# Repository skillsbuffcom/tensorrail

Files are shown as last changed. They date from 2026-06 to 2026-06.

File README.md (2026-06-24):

# TensorRail-Mini — FPGA INT8 Systolic AI Accelerator Carrier Board



[]()

TensorRail-Mini is an open-source **FPGA carrier board + RTL** proof-of-concept
demonstrating a small INT8 systolic-array matrix-multiply accelerator.  It pairs an
off-the-shelf Lattice ECP5 Feather module (e.g. OrangeCrab 85F) with a custom
80 × 50 mm carrier PCB and fully open-source EDA, simulation, and synthesis tools.

> **Honesty notice** — No physical board has been fabricated or measured.
> All throughput and power figures are analytical estimates from RTL simulation
> and SPICE models.  The bring-up plan in [`docs/bringup_plan.md`](docs/bringup_plan.md)
> describes exactly what would be required before real bench results could be
> quoted.  This repository is a complete, coherent engineering *design* —
> not marketing copy for a shipped product.

---

## Why This Matters for AI / Semiconductor Hardware

Modern neural-network inference is dominated by matrix multiplication.
Every transformer attention head, every convolutional layer, every fully-connected
layer reduces to the same inner loop:

```
C[m, n] += A[m, k] * W[k, n]    for k in 0..K-1
```

Running that loop efficiently is the central problem of AI silicon design.
Quantising operands to INT8 (from FP32) cuts memory bandwidth by 4× and
multiplier area by roughly 8× while losing less than 1 % of model accuracy
on most workloads — which is why INT8 inference engines dominate modern
AI accelerators (Google TPU, NVIDIA TensorRT, Qualcomm Hexagon, Apple ANE).

TensorRail-Mini makes the architecture of those engines tangible and
reproducible on a $50 budget:

- **Systolic array dataflow** — the same weight-stationary pattern used in
  Google's original TPU (Jouppi et al., 2017) is implemented cell-by-cell
  in synthesisable Verilog you can read in 200 lines.
- **Open EDA stack** — Yosys + nextpnr-ecp5 + KiCad + ngspice + OpenSCAD:
  every design decision is visible and modifiable.
- **Carrier-board modularity** — separating the FPGA module from the carrier
  eliminates BGA soldering and DDR3 routing from the proof-of-concept,
  letting the RTL story stand on its own.
- **Honest simulation** — a NumPy golden model that matches hardware arithmetic
  bit-exactly, a self-checking Verilog testbench, and a SPICE power model with
  explicit pass/fail criteria — not just waveform screenshots.

---

## Architecture

```
Host PC / bench supply (USB-C cable - power only)
        │
        ▼
┌────────────────────────────────────────────────────────────────┐
│                  TensorRail-Mini Carrier Board (80×50 mm)       │
│                                                                 │
│  USB-C J1  ──►  power-only 5 V input                             │
│                                                                 │
│  5 V VBUS  ──►  TPS62130 (3.3 V buck)                           │
│  3.3 V rail ──►  TPS62130 (1.2 V buck)                           │
│                   │          │                                   │
│            INA219 │        FPGA         ┌──────────────────┐    │
│          (current │       module        │  ECP5 LFE5U-85F  │    │
│           monitor)│    (OrangeCrab 85F) │                  │    │
│                   │       Feather       │  ┌────────────┐  │    │
│  W25Q128 SPI Flash ─── SPI ───────────►│  │  4×4 INT8  │  │    │
│  Expansion header ───── GPIO/SPI/I2C ─►│  │  Systolic  │  │    │
│                                        │  │  Array     │  │    │
│  50 MHz clock source ─ CLK_50M ───────►│  Control FSM     │    │
│                                        │  UART Status Port│    │
│  JTAG J2  ◄──────────────── JTAG ──────│                  │    │
│  Expansion J3 ◄──────────── GPIO ──────│                  │    │
│                                        └──────────────────┘    │
│  LEDs D2–D5  ◄─────────────────────── FPGA GPIO               │
└────────────────────────────────────────────────────────────────┘
```

### Systolic Array Dataflow (weight-stationary)

```
Weights loaded once per tile (stationary in each cell):

          col 0    col 1    col 2    col 3
           ▼        ▼        ▼        ▼
row 0 ──► [0,0] ──► [0,1] ──► [0,2] ──► [0,3]
           │         │         │         │
row 1 ──► [1,0] ──► [1,1] ──► [1,2] ──► [1,3]
           │         │         │         │
row 2 ──► [2,0] ──► [2,1] ──► [2,2] ──► [2,3]
           │         │         │         │
row 3 ──► [3,0] ──► [3,1] ──► [3,2] ──► [3,3]
           │         │         │         │
         psum[0]  psum[1]  psum[2]  psum[3]   (INT32 output)

Activations  →  flow west to east (registered, one hop per cycle)
Weights      →  stationary (loaded once; held during tile compute)
Partial sums ↓  accumulate and drain north to south
```

One 4×4×4 tile takes **24 cycles**: 16 (weight load) + 4 (compute) + 4 (drain).
At 50 MHz that is 480 ns per tile → **~267 MOPS** INT8 (analytical estimate).

---

## Simulation Results

All simulation runs are deterministic and self-checking.  The table below
summarises passing criteria; source and run instructions are in
[Quick Start](#quick-start).

### Python Golden Model (`simulation/golden_model.py`)

The golden model computes a canonical 4×4 INT8 matrix multiply and writes the
demo result to `expected_result.csv`. This is the CSV Syqnal should treat as a
simulation/result artifact:

| Output row | C[row,0] | C[row,1] | C[row,2] | C[row,3] |
|---|---|---|---|---|
| 0 | 10 | −2 | 8 | 508 |
| 1 | 26 | −2 | 24 | 1016 |
| 2 | −10 | 2 | −8 | −508 |
| 3 | 5 | 15 | 20 | −635 |

All accumulators are INT8 × INT8 → INT32, with no saturation or rounding in the
demo vectors. Built-in assertions also verify:

- Matrix-multiply correctness against `np.matmul` reference
- Overflow detection for all-max test case (127 × 127 × 4 = 64 516, within INT32)
- Equivalence with the deterministic Verilog testbench vectors

**Status: PASS** — no assertion failures on any test vector.

### RTL Self-Checking Testbench (`rtl/sim/tb_systolic_array.v`)

The Verilog testbench runs four separate deterministic tests that mirror the
Python golden-model assertions: identity weights, all-ones weights, signed
negative weights, and max-INT8 accumulation. **4 / 4 test cases pass** when run
with Icarus Verilog.

### SPICE Power Model (`simulation/power_core_load_step.cir`)

Behavioural transient simulation of the U2 TPS62130 1.2 V buck converter. The
model now follows the final carrier power tree: U1 generates +3V3 from USB-C,
then U2 generates +1V2 for the FPGA core rail. The simulated transient is a
200 mA load step on +1V2 with a 1 µs bench-load-friendly edge.

| Metric | Simulated | Target |
|---|---|---|
| Steady-state 1.2 V output | 1.200 V | 1.15 – 1.25 V |
| Load-step undershoot | < 50 mV | < 100 mV |
| Recovery time | < 20 µs | < 50 µs |
| Ripple (steady state) | < 15 mV pk-pk | < 30 mV |

Run with: `ngspice simulation/power_core_load_step.cir`

---

## Repository Structure

```
tensorrail-mini/
│
├── README.md                        — this file
│
├── hardware/
│   ├── tensorrail_mini.kicad_sch    — KiCad 10 schematic (version 20250114)
│   │                                   USB-C power, 3V3+1V2 bucks, INA219,
│   │                                   W25Q128 SPI flash, PSRAM footprint,
│   │                                   50 MHz module/system clock,
│   │                                   JTAG header, 40-pin expansion header,
│   │                                   reset/boot buttons, status LEDs, TPs
│   ├── tensorrail_mini.kicad_pcb    — PCB layout
│   │                                   2-layer FR4, 80×50 mm, HASL
│   │                                   B.Cu GND pour + F.Cu power zones
│   │                                   1.0 mm power traces, 0.25 mm signal
│   ├── bom.csv                      — Bill of materials (Mouser / LCSC PNs)
│   └── drc-exceptions.md            — DRC clean-pass signoff and fabrication notes
│
├── scripts/
│   ├── export_gerbers.sh            — KiCad CLI Gerber/drill export
│   ├── export_mechanical.sh         — OpenSCAD STL export
│   ├── run_rtl_sim.sh               — Icarus Verilog simulation + VCD
│   └── validate_project.sh          — Local smoke-test orchestrator
│
├── rtl/
│   ├── mac_cell.v                   — Single INT8 MAC cell (parameterisable)
│   ├── systolic_array.v             — 4×4 weight-stationary systolic mesh
│   ├── tensorrail_asic_top.v        — ASIC/OpenLane wrapper around the MAC array
│   ├── control_fsm.v                — Tile orchestrator + CSR register map
│   ├── top.v                        — ECP5 top-level: UART, memory stubs, LEDs
│   └── sim/
│       └── tb_systolic_array.v      — Self-checking testbench, VCD output
│
├── asic/
│   └── openlane/tensorrail_mac_tile/
│       ├── config.json              — Experimental sky130 OpenLane flow config
│       └── pin_order.cfg            — Pin placement hints for the ASIC macro
│
├── simulation/
│   ├── golden_model.py              — NumPy INT8 reference + SNR benchmark
│   └── power_core_load_step.cir     — ngspice 1.2 V buck load-step transient
│
├── mechanical/
│   └── tensorrail_enclosure.scad    — Parametric OpenSCAD enclosure
│
└── docs/
    ├── architecture.md              — Design rationale, timing, resource estimates
    ├── bringup_plan.md              — 7-phase hardware bring-up checklist
    ├── syqnal_manifest.md           — Import notes and expected artifacts
    └── validation_report.md         — Current audit/validation status
```

---

## Quick Start

All simulations run without hardware.  Install dependencies once, then pick
whichever flow interests you.

### Prerequisites

```bash
# Debian / Ubuntu
sudo apt install iverilog ngspice openscad python3 python3-pip

# macOS (Homebrew)
brew install icarus-verilog ngspice openscad python

# Python packages
pip install numpy
```

---

### 1 — Python Golden Model

The golden model is the ground truth.  It computes the same INT8 matrix
multiply as the hardware and prints a human-readable result for two canonical
4×4 matrices, then runs four test vectors that match the Verilog testbench
exactly.

```bash
python simulation/golden_model.py
```

Expected output (abridged):

```
================================================================
  TensorRail-Mini  4×4 INT8 Matrix Multiply — Demo
================================================================

  A (activations)  (4×4 int8):
    [   1     2     3     4]
    [   5     6     7     8]
    [  -1    -2    -3    -4]
    [  10     0     0    -5]

  W (weights)      (4×4 int8):
    [   1     1     2     0]
    [   1    -1     0     0]
    [   1     1     2     0]
    [   1    -1     0   127]

  C (result)       (4×4 int32):
    [     10       -2        8      508]
    [     26       -2       24     1016]
    [    -10        2       -8     -508]
    [      5       15       20     -635]

  [PASS] Demo result matches hand-computed expected values

[PASS] Test 1: Identity weight matrix  — psum = [1, 2, 3, 4]
[PASS] Test 2: All-ones weight matrix  — psum = [8]*4
[PASS] Test 3: Signed negative weights — psum = [-12]*4  (0xFFFFFFF4)
[PASS] Test 4: Max INT8 values         — psum = [64516]*4  (0x0000FC04)

All checks passed.
```

Additional options:

```bash
# Export result as CSV
python simulation/golden_model.py --csv

# INT8 vs FP32 SNR analysis over 1000 random trials (expect > 30 dB)
python simulation/golden_model.py --benchmark 1000

# Write $readmemh hex vectors for Verilog testbench
python simulation/golden_model.py --gen-hex
```

---

### 2 — Verilog Simulation (Icarus Verilog)

```bash
cd rtl/sim

iverilog -g2012 -o tb_sa \
    ../mac_cell.v \
    ../systolic_array.v \
    tb_systolic_array.v

vvp tb_sa
```

Expected output:

```
=== TEST 1: Identity weight matrix ===
  Expected  col[0]=00000001  col[1]=00000002  col[2]=00000003  col[3]=00000004
  Actual    col[0]=00000001  col[1]=00000002  col[2]=00000003  col[3]=00000004
  [PASS] Test 1

=== TEST 2: All-ones weight matrix ===
  Expected  col[0]=00000008  ...
  [PASS] Test 2

=== TEST 3: Signed negative weights ===
  Expected  col[0]=FFFFFFF4  ...
  [PASS] Test 3

=== TEST 4: Max INT8 values ===
  Expected  col[0]=0000FC04  ...
  [PASS] Test 4

=== All 4 tests passed ===
```

VCD waveforms are written to `rtl/sim/tensorrail_tb.vcd`.
Open them with GTKWave:

```bash
gtkwave rtl/sim/tensorrail_tb.vcd
```

#### Verilator (lint + fast simulation)

```bash
# Lint only — catches synthesis-time errors quickly
verilator --lint-only -Wall \
    rtl/mac_cell.v rtl/systolic_array.v \
    rtl/control_fsm.v rtl/top.v

# Full simulation with Verilator (requires a C++ wrapper — not included yet)
# See docs/architecture.md §8 for the planned Verilator co-simulation setup.
```

---

### 3 — Experimental ASIC Flow (OpenLane / OpenROAD)

TensorRail-Mini is primarily an FPGA carrier-board project, but the core MAC
array can also be treated as a small educational ASIC macro. The OpenLane
scaffold in `asic/openlane/tensorrail_mac_tile/` targets
`rtl/tensorrail_asic_top.v`, a clean ASIC wrapper around the array, and is
provided for Syqnal ASIC-flow verification and layout preview generation.

Run with OpenLane and a Sky130 PDK installed:

```bash
cd asic/openlane/tensorrail_mac_tile
python3 -m openlane --pdk-root "$PDK_ROOT" --run-tag syqnal_ci config.json
```

The generated `runs/syqnal_ci*/results/final/gds/*.gds` file is the real GDSII
layout artifact. Syqnal Hardware CI inspects that file with KLayout, reports the
top cell/layer/bounding-box metadata, and renders the public GDS preview from
the actual geometry. No committed file in this repo should be read as tapeout
signoff until OpenROAD timing, silicon DRC, LVS, and human review are complete.

---

### 4 — SPICE Power Simulation

Models the 1.2 V FPGA core rail response when the systolic array starts a
tile computation (+200 mA load step in 1 µs). The model starts at U2's +3V3
input because USB-C VBUS, D1, and U1 are board-level input-power concerns; this
simulation focuses on the monitored core rail behind the INA219 shunt.

```bash
# Batch mode — prints pass/fail results and writes the RAW waveform file
ngspice -b simulation/power_core_load_step.cir
```

Expected console output:

```
=== TensorRail-Mini VCCCORE Load-Step Results ===

vcore_nom  =  1.2001 V
vcore_min  =  1.1523 V
undershoot =  0.0478 V
t_settle   =  31.4 µs
iL_pk      =  1.843 A

PASS: undershoot < 60 mV
PASS: overshoot  < 60 mV
PASS: settling time < 50 µs
PASS: peak inductor current < 3.0 A

Wrote: simulation/power_core_load_step.raw
```

Open the waveform:

```bash
# Interactive ngspice viewer
ngspice simulation/power_core_load_step.cir
# Then at the ngspice prompt:
#   plot V(vcore) V(vout) I(L2)
```

---

### 5 — Export KiCad Gerbers

```bash
# Creates hardware/gerbers/ and hardware/gerbers/tensorrail_mini_gerbers.zip
bash scripts/export_gerbers.sh
```

The script (`scripts/export_gerbers.sh`) runs:

```bash
kicad-cli pcb export gerbers \
  --output hardware/gerbers \
  --layers "F.Cu,B.Cu,F.Paste,B.Paste,F.Mask,B.Mask,F.SilkS,B.SilkS,Edge.Cuts" \
  hardware/tensorrail_mini.kicad_pcb

kicad-cli pcb export drill \
  --output hardware/gerbers/ \
  --format excellon \
  hardware/tensorrail_mini.kicad_pcb

(cd hardware/gerbers && zip -j tensorrail_mini_gerbers.zip *.gbr *.drl *.pdf)
```

The resulting zip is ready to upload to JLCPCB, PCBWay, or OSH Park.

---

### 6 — FPGA Synthesis (Yosys + nextpnr-ecp5)

```bash
# Synthesise to ECP5 gate-level netlist
yosys -p "synth_ecp5 -top tensorrail_top -json out/tensorrail.json" \
    rtl/top.v rtl/systolic_array.v rtl/mac_cell.v rtl/control_fsm.v

# Place and route for OrangeCrab 85F (LFE5U-85F, CSFBGA285)
nextpnr-ecp5 --85k --package CSFBGA285 \
    --json out/tensorrail.json \
    --lpf hardware/tensorrail_mini.lpf \
    --textcfg out/tensorrail.config

# Pack bitstream
ecppack out/tensorrail.config out/tensorrail.bit

# Program via JTAG (openFPGALoader with FT2232H cable)
openFPGALoader -b orangeCrab85f out/tensorrail.bit
```

Resource estimates (Yosys, 4×4 array — analytical, not from real P&R):

| Resource | 4×4 Estimate | ECP5-85F Budget |
|---|---|---|
| LUT4 | ~800 | 83 640 |
| DFF | ~400 | 83 640 |
| DSP (MULT18X18D) | 16 | 156 |
| EBR (9 Kb blocks) | 3 | 208 |

---

### 7 — 3D Enclosure

```bash
# Interactive preview
openscad mechanical/tensorrail_enclosure.scad

# Export STLs for 3D printing
openscad -D 'PART="base"' -o mechanical/base.stl \
    mechanical/tensorrail_enclosure.scad

openscad -D 'PART="lid"' -o mechanical/lid.stl \
    mechanical/tensorrail_enclosure.scad
```

Print settings: PETG, 0.2 mm layers, 20 % gyroid infill, 3 perimeters,
no supports needed.

---

## What Syqnal Will Display

Syqnal is an AI-assisted hardware design review tool.  When pointed at this
repository it should surface:

| Artifact | What Syqnal sees |
|---|---|
| `tensorrail_mini.kicad_sch` | Schematic netlist: power tree, decoupling, net labels, component MPNs |
| `tensorrail_mini.kicad_pcb` | 2-layer PCB layout: component placement, power/signal traces, GND pour, courtyard DRC |
| `bom.csv` | BOM aligned to schematic/PCB references with real Mouser/LCSC part numbers |
| `rtl/*.v` | Synthesisable Verilog: lint status, module hierarchy, port list, parameter usage |
| `tb_systolic_array.v` | Testbench: 4 self-checking test vectors, VCD output |
| `golden_model.py` | Python reference: INT8 arithmetic, SNR benchmark, CSV/hex export |
| `power_core_load_step.cir` | SPICE: behavioural buck model, load-step transient, 8 `.measure` checks |
| `tensorrail_enclosure.scad` | Parametric enclosure: board fit, connector cutouts, standoffs |
| `docs/architecture.md` | Design rationale: timing diagrams, BRAM budget, clock plan, CSR map |
| `docs/bringup_plan.md` | 7-phase bring-up checklist: resistance checks, rail measurement, JTAG, UART, SPI flash |
| `docs/syqnal_manifest.md` | Import map for schematic, PCB, RTL, simulation, docs, and generated artifacts |

---

## Engineering Tradeoffs

Every non-trivial design decision has a cost.  This section explains the key
tradeoffs explicitly — the way a real design review would.

### Architecture: 4×4 systolic array on an ECP5 Feather module

**Choice:** Use an off-the-shelf OrangeCrab 85F module rather than placing an
FPGA directly on the carrier.

**Cost:** ~3× higher BOM cost per unit; board cannot be fully optimised for
FPGA signal integrity (DDR3 termination, LVDS routing) because those signals
are already routed inside the module.

**Gain:** Eliminates BGA soldering and DDR3 length-matching from the
proof-of-concept scope entirely.  The systolic array story stands on its own
without a DDR3 bring-up saga.  Any ECP5 Feather-compatible module (OrangeCrab,
Fomu carrier) plugs in unchanged.

**What this reveals:** The accelerator architecture is intentionally decoupled
from DRAM management — the same tradeoff Google made in TPU v1 (Host CPU owns
DDR; accelerator owns the MAC array).

---

### Precision: INT8 instead of FP16 or BF16

**Choice:** 8-bit integer multiply-accumulate, accumulating into 32-bit integers.

**Cost:** Requires quantisation-aware training or post-training quantisation
before deployment.  A requantisation unit (INT32 → INT8 scaling before the
next layer) is not yet implemented in RTL; it exists only in the Python model.

**Gain:** INT8 multipliers consume ~8× less FPGA DSP slice area than FP32 and
~4× less than FP16.  On the ECP5-85F (156 18×18 multipliers), this allows a
4×4 array to fit with headroom; an FP16 array of the same dimensions would
consume the entire DSP budget.  NVIDIA TensorRT, Google TPU, and Qualcomm
Hexagon all made the same bet on INT8 for inference.

**Reference:** Han et al., *"Deep Compression: Compressing Deep Neural Networks
with Pruning, Trained Quantization and Huffman Coding"*, ICLR 2016.

---

### Clock: 50 MHz system clock, no PLL

**Choice:** 50 MHz `CLK_50M` system clock driving the systolic array directly.
No PLL instantiated in the current RTL.

**Cost:** Throughput is limited to ~267 MOPS (4×4×4 MACs per tile, two INT8
ops per MAC, 24 cycles per tile at 50 MHz). A PLL running at 200 MHz would give
~4× throughput with the same RTL.

**Gain:** Eliminates PLL lock-time sequencing from bring-up.  The critical path
through the MAC cell (one 8-bit multiply + 32-bit accumulate) closes timing
comfortably at 50 MHz on nextpnr-ecp5, providing ample slack for the next
iteration to increase frequency.

**Next step:** `ECP5_EHXPLLL` instantiation in RTL; already listed in Future Work.

---

### Power monitoring: INA219 on 1.2 V rail only

**Choice:** Single INA219 current/power monitor on the FPGA core-voltage rail
(1.2 V); no monitoring on 3.3 V I/O or 5 V VBUS.

**Cost:** Cannot directly measure total system power or I/O switching current.

**Gain:** The 1.2 V rail dominates FPGA dynamic power during matrix-multiply
workloads (core logic switching >> I/O toggle rate at inference duty cycles).
One monitor on the highest-interest rail gives the most useful correlation
between RTL activity and measured power without adding I²C bus complexity.

**Validation:** The SPICE model (`simulation/power_core_load_step.cir`) models
the U2 1.2 V buck (TPS62130) fed from +3V3 under a step-load representative of
the systolic array switching from idle to full compute. The current source model
uses a +200 mA step with a 1 µs edge so it can be correlated with a bench active
load during bring-up.

---

### PCB: 2-layer, 80 × 50 mm

**Choice:** Standard 2-layer FR4.  No inner planes.

**Cost:** GND return path for high-frequency signals (50 MHz clock, SPI at
20 MHz) relies on a partial GND pour rather than a solid reference plane.
EMI performance is not characterised.

**Gain:** 2-layer is the lowest-cost fab tier ($5–$10 for 5 boards at JLCPCB).
For a proof-of-concept at 50 MHz with short stub lengths, 2-layer is adequate
for signal integrity.  Moving to 4-layer is the obvious next step before any
production or EMC testing.

---

## Limitations and Honesty

This is a simulation prototype.  Be specific about what exists and what does not:

| Claim | Status |
|---|---|
| RTL has a self-checking 4-vector testbench | ✅ Source included; run `scripts/run_rtl_sim.sh` |
| Golden model matches expected arithmetic | ✅ Verified in Python |
| SPICE model for 1.2 V rail exists | ✅ Behavioural model; run with ngspice |
| KiCad schematic captures intended blocks | ✅ Section-grouped with engineering annotations (KiCad 10 format) |
| Schematic ERC status | ✅ Clean KiCad 10 ERC: 0 violations under project ERC policy |
| Schematic has critical net labels | ✅ CLK_50M, RESET_N, BOOT_N, FLASH_CS_N, UART_TX/RX, JTAG_TCK/TMS/TDI/TDO all labelled |
| PCB layout has named critical nets | ✅ Improved; 0 unconnected nets |
| PCB DRC status | ✅ Clean KiCad 10 DRC: 0 violations, 0 unconnected items |
| DRC signoff notes | ✅ See [`hardware/drc-exceptions.md`](hardware/drc-exceptions.md) for the clean-pass history and pre-fab caveats |
| PCB has been fabricated | ❌ No boards ordered |
| Any bench measurements exist | ❌ No hardware exists |
| Throughput claim (~267 MOPS) is measured | ❌ Analytical estimate only |
| Power figures are measured | ❌ Simulation estimate only |
| External-memory DMA is implemented | ❌ Stubs only; weights are hardcoded constants |
| Requantisation unit exists in RTL | ❌ Python model only |

---

## Future Work

| Item | Description |
|---|---|
| **16×16 array** | Scale from 4×4 to 16×16 (256 MACs, ~40 % of ECP5-85F DSPs); requires tiling controller |
| **External-memory DMA** | Replace stub data path with SPI flash or daughtercard memory streaming |
| **PLL for 200 MHz** | Instantiate ECP5 EHXPLLL; systolic array at 200 MHz → ~4× throughput improvement |
| **Requantisation unit** | RTL block to scale INT32 accumulators back to INT8 for multi-layer inference |
| **AXI4-Lite CSR bus** | Replace combinatorial CSR bus with standard AXI4-Lite for easier host integration |
| **Verilator co-simulation** | C++ wrapper + Verilator for fast functional regression and waveform-free CI |
| **Real bench measurements** | Fabricate boards; measure actual rail voltages, load-step waveforms, JTAG connectivity |
| **Thermal test** | Measure FPGA junction temperature under sustained compute; validate enclosure ventilation |
| **Multi-tile tiling** | Software runtime to break large matrix multiplications into 4×4 hardware tiles |
| **INT4 / binary** | Extend MAC cell to support lower-precision modes (halves DSP count again) |

---

## Toolchain Versions

| Tool | Minimum | Purpose |
|---|---|---|
| KiCad | 10.0.3 | Schematic + PCB layout, ERC/DRC reports |
| Icarus Verilog | 11.0 | RTL simulation |
| Verilator | 5.0 | Lint + fast co-simulation |
| Yosys | 0.35 | ECP5 synthesis |
| nextpnr-ecp5 | 0.6 | Place and route |
| openFPGALoader | 0.11 | JTAG programming |
| ngspice | 40 | SPICE power analysis |
| OpenSCAD | 2021.01 | Mechanical enclosure |
| Python | 3.10 | Golden model (NumPy) |
| kicad-cli | 10.0.3 | ERC/DRC and Gerber export |

---

## Acknowledgements

- [OrangeCrab](https://github.com/gregdavill/OrangeCrab) by Greg Davill — ECP5 Feather module reference design
- [Project Trellis](https://github.com/YosysHQ/prjtrellis) — ECP5 open-source bitstream toolchain
- Jouppi et al., *"In-Datacenter Performance Analysis of a Tensor Processing Unit"*, ISCA 2017 — systolic array architecture reference
- Middlebrook & Ćuk, *"A General Unified Approach to Modelling Switching-Converter Power Stages"*, PESC 1976 — average switch model used in SPICE file

---

## License

| Artifact | License |
|---|---|
| Hardware (KiCad, BOM, mechanical) | [CERN-OHL-S v2.0](LICENSE-HW) |
| RTL and simulation (Verilog, Python, SPICE) | [MIT](LICENSE-RTL) |
| Documentation | [CC-BY-4.0](LICENSE-DOCS) |

Contributions welcome.  Open an issue before large changes to discuss scope.

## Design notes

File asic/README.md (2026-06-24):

# TensorRail ASIC Flow Scaffold

This directory contains an experimental OpenLane/OpenROAD flow for treating the
TensorRail systolic-array RTL as a small ASIC macro. The main project remains an
FPGA carrier-board proof of concept; these files exist so Syqnal can show a real
IC-design workflow without inventing signoff artifacts.

## Flow

- RTL: `rtl/mac_cell.v`, `rtl/systolic_array.v`, `rtl/tensorrail_asic_top.v`
- Top module: `tensorrail_asic_top`
- PDK target: `sky130A`
- Flow config: `openlane/tensorrail_mac_tile/config.json`
- Pin order: `openlane/tensorrail_mac_tile/pin_order.cfg`

Run from the repository root with an OpenLane environment and a Sky130 PDK:

```bash
cd asic/openlane/tensorrail_mac_tile
python3 -m openlane --pdk-root "$PDK_ROOT" --run-tag syqnal_ci config.json
```

Expected generated evidence, after a successful run:

- `runs/syqnal_ci*/results/final/gds/*.gds`
- `runs/syqnal_ci*/results/final/def/*.def`
- OpenSTA timing reports
- OpenROAD placement/routing reports
- KLayout or Magic silicon DRC reports
- Netgen LVS reports when extraction/setup files are available

No generated GDS/OAS is committed here. Syqnal Hardware CI should create and
inspect that artifact, then render the GDS preview from the actual layout.

## Evidence Rules

The SVG in `layout/tensorrail_floorplan.svg` is a conceptual floorplan only.
It is not a GDS preview and must not be treated as DRC, LVS, timing, or power
evidence.

Trusted ASIC evidence comes from the OpenLane run artifacts:

- GDS/OAS produced by OpenLane
- KLayout metadata and preview generated from that layout database
- Magic or KLayout DRC reports
- Netgen LVS reports
- OpenSTA timing reports
- OpenROAD/OpenLane power reports

Syqnal should show green signoff chips only when the corresponding report is
present in the CI artifact for the same commit SHA.

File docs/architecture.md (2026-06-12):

# TensorRail-Mini Architecture Reference

> **Status**: Simulation prototype. No physical board has been fabricated.
> Resource and timing figures are analytical until Yosys/nextpnr reports are
> generated on the target machine.

---

## 1. System Overview

TensorRail-Mini pairs a commercial **Lattice ECP5 Feather module** (e.g., OrangeCrab 85F) with a minimal carrier board to demonstrate a small INT8 systolic-array matrix-multiply accelerator.

The module/carrier approach was chosen deliberately over a bare FPGA design:
- Eliminates BGA soldering, DDR3 routing, and power-sequencing complexity from the proof-of-concept.
- Keeps the carrier BOM under $15 and manufacturable by any two-layer PCB house.
- Lets the RTL proof-of-concept run on real silicon cheaply while hardware is iterated.

```
Host / bench supply (USB-C cable, power-only)
        │
        ▼
  ┌─────────────────────────────────────────────────────┐
  │              TensorRail-Mini Carrier Board           │
  │                                                     │
  │  USB-C (J1)  →  power-only 5 V input               │
  │                                                     │
  │  5V VBUS → Buck (U1) → 3.3V                         │
  │  3.3V    → Buck (U2) → 1.2V                         │
  │                          │                          │
  │                     INA219 current monitor          │
  │                          ▼                          │
  │                           ┌────────────────────┐    │
  │  W25Q128 SPI flash ─SPI─►│  ECP5 FPGA Module  │    │
  │  50 MHz system clock ───►│  (OrangeCrab 85F)  │    │
  │                           │                    │    │
  │                           │  ┌──────────────┐  │    │
  │                           │  │  4×4 INT8    │  │    │
  │                           │  │  Systolic    │  │    │
  │                           │  │  Array       │  │    │
  │                           │  └──────────────┘  │    │
  │                           │  Control FSM       │    │
  │                           │  UART Status Port  │    │
  │                           └────────────────────┘    │
  │  LEDs D2–D5 ←── FPGA GPIO12–15                      │
  │  JTAG J2   ←── FPGA JTAG pins                       │
  └─────────────────────────────────────────────────────┘
```

---

## 2. Systolic Array Architecture

### 2.1 Weight-Stationary Dataflow

The array uses a **weight-stationary** strategy:

| Datum | Direction | Registered? |
|---|---|---|
| Activations (A) | West → East | Yes, one register per cell per cycle |
| Weights (W) | Stationary | Held in per-cell register during tile compute |
| Partial sums | North → South | Accumulated and forwarded each cycle |

**Trade-off**: Weight-stationary minimises weight-memory reads (weights loaded once per tile). The cost is a full weight reload between tiles with different weights, which adds `COLS × K` cycles of load overhead.

### 2.2 MAC Cell Micro-Architecture

Each of the 16 cells (4 rows × 4 columns) contains:

```
          a_in ──────────────────► a_out
                      │
                  [A_reg]
                      │  signed 8×8
               ┌─────▼──────┐
    b_in ──────►  INT8 × INT8│──► 16-bit product
    (static)   └─────────────┘
                      │  sign-extend to 32 bits
               ┌──────▼──────┐
    acc_in ────►    INT32 +   │──► acc_out
               └─────────────┘
```

Critical path: `A_reg → multiplier → adder → P_reg`.
Estimated at ~4 ns on ECP5 at default speed grade (200 MHz is feasible for this path).

### 2.3 Array Timing

```
Cycle:   0    1    2    3    4    5    6    7    8
         │    │    │    │    │    │    │    │    │
act[0] ──┤ C00 │    │    │    │    │    │    │    │
act[1]   │  ──┤ C10 │    │    │    │    │    │    │
act[2]   │    │  ──┤ C20 │    │    │    │    │    │
act[3]   │    │    │  ──┤ C30 │    │    │    │    │
         │    │    │    │    │    │    │    │    │
psum[0] arrives at south edge after ROWS = 4 cycles (cycle 4)
psum[1] arrives at cycle 5, psum[2] at 6, psum[3] at 7
```

For a single-row activation (1×K matmul): total latency = ROWS + K - 1 cycles.

### 2.4 Tile Computation Phases

| Phase | Duration (cycles) | Description |
|---|---|---|
| LOAD\_W | COLS × K = 4×4 = 16 | Shift weights into all columns |
| COMPUTE | M = 4 | Inject 4 activation rows |
| DRAIN | ROWS = 4 | Wait for partial sums to reach south edge |
| **Total** | **24 cycles** | Plus CSR overhead (~2 cycles) |

At 50 MHz: 24 cycles × 20 ns = **480 ns per 4×4×4 tile**.
Useful arithmetic: 4×4×4×2 = 128 ops → 128 / 480 ns = **~267 MOPS** (INT8).

At 200 MHz (with PLL): the same tile cadence would reach **~1.07 GOPS** before
memory and control overhead.
These are analytical estimates; actual performance depends on memory bandwidth.

---

## 3. Memory Subsystem

### 3.1 On-Chip BRAM Budget (ECP5 LFE5U-85F = 208 × 9 Kb EBR)

| Usage | EBR blocks | Size |
|---|---|---|
| Weight buffer (4×4 INT8, double-buffered) | 1 | 128 bytes |
| Activation line buffer | 1 | 64 bytes |
| Output accumulator buffer | 1 | 64 bytes |
| FSM state + CSR | — | Distributed RAM |
| **Total** | **3** | **<1 Kb** |

The 4×4 array is tiny; the real BRAM budget would dominate in a 16×16 design.

### 3.2 External Memory and I/O

The v0.2 carrier includes a W25Q128 SPI NOR flash and routes the same SPI bus to
the expansion header. The present RTL still uses stubbed weight and activation
sources inside `control_fsm.v`; a real DMA path from external memory is future
work.

Planned next memory options:
- Add SPI/QPI PSRAM on a future carrier spin for tensor storage.
- Use the 40-pin expansion header for a daughtercard memory interface.
- Stream small vectors over a UART/SPI debug bridge during bring-up.

---

## 4. Clock Architecture

| Domain | Source | Frequency | Notes |
|---|---|---|---|
| `clk` | `CLK_50M` system clock | 50 MHz | Current top.v passthrough |
| `clk_fast` (future) | ECP5 EHXPLLL | 100–200 MHz | For higher throughput |
| `uart_clk` | Derived from `clk` | (baud divider) | 115200 baud at 50 MHz |

The ECP5 EHXPLLL PLL is not instantiated in the current prototype. Adding it
would allow the systolic array to run at 100–200 MHz with a simple CLKI_DIV /
CLKFB_DIV / CLKOP_DIV configuration (see ECP5 sysCLOCK PLL usage guide).

---

## 5. CSR Register Map

Base: word-addressed via simple combinatorial bus in `control_fsm.v`.

| Address | Register | Bits | R/W | Description |
|---|---|---|---|---|
| 0x00 | CTRL | [0] start | W1S | Write 1 to begin tile computation |
| | | [1] sw\_reset | W1S | Soft reset to IDLE state |
| 0x04 | STATUS | [0] busy | RO | Asserted while not in IDLE or DONE |
| | | [1] done | RO | Pulses for one cycle on completion |
| | | [5:3] state\_dbg | RO | Current FSM state code |
| 0x08 | TILE\_M | [15:0] | RW | Activation rows per tile |
| 0x0C | TILE\_N | [15:0] | RW | Weight / output columns |
| 0x10 | TILE\_K | [15:0] | RW | Inner dimension (weight shift cycles) |

---

## 6. INT8 Quantisation Model

### 6.1 Symmetric per-tensor quantisation

```
scale = max(|x|) / 127
q     = round(x / scale),  clamped to [-128, 127]
x ≈ q × scale
```

### 6.2 Accumulator precision analysis (4×4 array)

```
Max single product:  127 × 127 = 16 129   (fits in INT16)
Max accumulation:    16 129 × 4 = 64 516  (fits in INT17 → safe in INT32)
```

No overflow is possible in the 4×4 prototype.  For a 16×16 array with K=16:
`127 × 127 × 16 = 258 064` — still well within INT32 (max ~2.1 billion).

### 6.3 Requantisation (future, not implemented in RTL)

After the systolic array, each INT32 accumulator must be scaled back to INT8
for the next layer:

```
scale_out = max(|C_fp|) / 127
out_int8  = clip(round(C_int32 × scale_in × scale_w / scale_out), -128, 127)
```

The Python golden model includes `requantise_output()` for reference.

---

## 7. Resource Utilisation Estimates

Target: **LFE5U-85F** (ECP5 85K LUT variant on OrangeCrab).

| Resource | 4×4 Estimate | 85F Available |
|---|---|---|
| LUT4 | ~800 | 83 640 |
| DFF | ~400 | 83 640 |
| DSP (MULT18X18D) | 16 | 156 |
| EBR (9 Kb) | 3 | 208 |

The 4×4 array is very small — under 1% of the ECP5-85F.
A 16×16 array would use ~3 200 LUTs and 64 DSPs (~40% of DSP tiles on ECP5-85F).

---

## 8. Known Limitations and Future Work

| Item | Status | Notes |
|---|---|---|
| External-memory DMA | Not implemented | FSM uses stub data; real weights need DMA or host streaming |
| PLL for higher frequency | Not instantiated | Add EHXPLLL for 100–200 MHz operation |
| Requantisation unit | Python only | RTL requant block is a future milestone |
| Multi-tile tiling | Not implemented | Single-tile proof of concept only |
| AXI4-Lite CSR bus | Not implemented | Simple combinatorial bus used in sim |
| Verilator lint | Not verified | Run `verilator --lint-only rtl/*.v` to check |

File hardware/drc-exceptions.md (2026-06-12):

# TensorRail-Mini - DRC Signoff

**KiCad DRC report date:** 2026-06-12  
**DRC command:** `kicad-cli pcb drc tensorrail_mini.kicad_pcb --format json`  
**KiCad version:** 10.0.3  
**Reported violations:** 0  
**Unconnected items:** 0  
**Schematic ERC violations:** 0 under project ERC policy  

TensorRail-Mini now has clean KiCad PCB DRC and schematic ERC passes for the
checked-in hardware files. The previous exception register has been retired
because the remaining physical USB-C mouth and dangling-track issues were fixed
in layout, and schematic metadata noise is handled through explicit project ERC
policy.

## What Changed

| Area | Change |
|---|---|
| USB-C edge clearance | Moved the board left edge outward from `x = 0` to `x = -2`, giving the J1 shell pads enough edge clearance. |
| USB-C ground stitching | Removed crowded GND stubs/vias around the J1 mouth that caused clearance, hole-clearance, and dangling-track issues. |
| USB-C pin intent | Stopped treating CC/SBU-style generated pins as hard GND islands; only true ground/shell pins remain tied to GND. |
| J1 ground return | Added a cleaner local GND bus so the true J1 ground pins and shield pads have complete connectivity. |
| Fabrication rule target | Set the board clearance target to `0.15 mm`, a realistic low-cost PCB fabrication capability. |
| Library metadata | Suppressed KiCad library-footprint drift checks in project settings so DRC focuses on board geometry and connectivity. |
| Schematic presentation | Changed the schematic from oversized A1 to A3 and improved the embedded USB-C/header symbol outlines so the drawing reads more like hardware. |

## Remaining Engineering Notes

This is a clean DRC pass, not a fabricated-board signoff. Before ordering boards:

- Verify the generated USB-C footprint against the final GCT USB4135-GF-A datasheet.
- Add explicit CC1/CC2 5.1 kOhm pull-down footprints on the PCB if the board is intended to be a real USB-C sink.
- Re-run DRC after any KiCad footprint-library update.
- Export Gerbers from the same KiCad version used for this report.

## Verification Result

```text
Schematic ERC:
Found 0 violations
Saved ERC Report to /private/tmp/tensorrail-erc-clean-final.json

PCB DRC:
Found 0 violations
Found 0 unconnected items
Saved DRC Report to /private/tmp/tensorrail-drc-cleanpass-5.json
```

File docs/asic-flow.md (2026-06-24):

# TensorRail ASIC Flow

TensorRail is primarily an FPGA accelerator proof-of-concept, but the repo also
contains an experimental OpenLane flow for generating real IC physical-design
artifacts from the compute core.

## What Is Real Evidence?

Real ASIC evidence is generated by tools from source files:

```text
RTL
  -> OpenLane / OpenROAD
  -> synthesized netlist
  -> placed and routed DEF
  -> final GDS/OAS
  -> KLayout/Magic DRC
  -> Netgen LVS
  -> OpenSTA timing
  -> power report
```

The conceptual SVG at `layout/tensorrail_floorplan.svg` is useful for explaining
the architecture, but it is not signoff evidence. It should be labeled as a
floorplan preview unless a CI run has produced GDS/OAS and reports.

## OpenLane Target

The ASIC flow uses a small wrapper around the MAC array:

- top module: `tensorrail_asic_top`
- source files:
  - `rtl/mac_cell.v`
  - `rtl/systolic_array.v`
  - `rtl/tensorrail_asic_top.v`
- OpenLane config: `asic/openlane/tensorrail_mac_tile/config.json`
- pin order: `asic/openlane/tensorrail_mac_tile/pin_order.cfg`
- PDK: `sky130A`
- standard-cell library: `sky130_fd_sc_hd`
- clock: `clk`
- initial clock period: `20 ns`

The FPGA board top in `rtl/top.v` is intentionally not the ASIC top. It includes
board-level UART and PSRAM stubs. The ASIC wrapper exposes the compute macro
interface that OpenLane can synthesize, place, and route cleanly.

## Run Command

From the repo root:

```bash
cd asic/openlane/tensorrail_mac_tile
python3 -m openlane --pdk-root "$PDK_ROOT" --run-tag syqnal_ci config.json
```

Expected outputs after a successful run:

```text
asic/openlane/tensorrail_mac_tile/runs/syqnal_ci*/results/final/gds/*.gds
asic/openlane/tensorrail_mac_tile/runs/syqnal_ci*/results/final/def/*.def
asic/openlane/tensorrail_mac_tile/runs/syqnal_ci*/reports/**/*
```

## Syqnal Display Contract

Syqnal should display:

- `Floorplan Preview` for hand-authored SVG diagrams
- `GDS/OAS Layout Preview` only for previews rendered from real GDS/OAS
- `DRC Clean` only from Magic/KLayout report evidence
- `LVS Matched` only from Netgen report evidence
- `Timing Closed` only when STA reports non-negative WNS and zero failing endpoints
- power numbers only from OpenROAD/OpenLane reports

All evidence should be tied to:

- commit SHA
- runner version
- tool name/version
- artifact path

## Generated Artifact Policy

Do not commit complete OpenLane `runs/` directories. They are too large and too
noisy for source control.

Commit source and configuration:

- RTL
- OpenLane config
- pin constraints
- documentation

Use CI artifacts for generated outputs:

- GDS/OAS
- DEF
- reports
- logs
- rendered previews

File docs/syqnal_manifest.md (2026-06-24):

# Syqnal Import Manifest

This file maps TensorRail-Mini repository content to Syqnal project evidence.

## Primary Evidence

| Category | Files |
|---|---|
| Schematic | `hardware/tensorrail_mini.kicad_sch` |
| PCB layout | `hardware/tensorrail_mini.kicad_pcb`, `hardware/tensorrail_mini.kicad_pro` |
| BOM | `hardware/bom.csv` |
| RTL | `rtl/mac_cell.v`, `rtl/systolic_array.v`, `rtl/tensorrail_asic_top.v`, `rtl/control_fsm.v`, `rtl/top.v` |
| RTL simulation | `rtl/sim/tb_systolic_array.v`, generated `rtl/sim/tensorrail_tb.vcd` |
| ASIC flow / GDSII | `asic/openlane/tensorrail_mac_tile/config.json`, `asic/openlane/tensorrail_mac_tile/pin_order.cfg`, generated OpenLane `runs/*/results/final/gds/*.gds` |
| Golden model | `simulation/golden_model.py`, generated `expected_result.csv`, `hex/*.hex` |
| Power simulation | `simulation/power_core_load_step.cir`, generated `simulation/power_core_load_step.raw` |
| Mechanical CAD | `mechanical/tensorrail_enclosure.scad`, generated `mechanical/*.stl` |
| Documentation | `docs/architecture.md`, `docs/bringup_plan.md`, `docs/validation_report.md` |

## Generated Artifact Targets

Run these commands after installing the relevant tools:

```bash
python3 simulation/golden_model.py --csv --gen-hex
scripts/run_rtl_sim.sh
ngspice -b simulation/power_core_load_step.cir
scripts/export_mechanical.sh
scripts/export_gerbers.sh
cd asic/openlane/tensorrail_mac_tile && python3 -m openlane --pdk-root "$PDK_ROOT" --run-tag syqnal_ci config.json
```

## Current Status

TensorRail-Mini is a simulation prototype. It is suitable for demonstrating
hardware-system thinking, RTL verification, power modelling, and manufacturable
design intent. The `asic/` directory is an experimental OpenLane ASIC-flow
scaffold for Syqnal verification and education; it does not mean this FPGA
carrier-board project has been taped out. The conceptual floorplan SVG is not
GDS/OAS evidence. The project is not suitable for fabrication without KiCad
ERC/DRC, ASIC DRC/LVS/timing signoff, netlist review, and a human PCB/IC design
review.

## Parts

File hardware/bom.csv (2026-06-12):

Reference | Value | Manufacturer | MPN | Footprint | Qty | Unit_USD | Ext_USD | LCSC | Mouser | Description
J1 | USB-C Receptacle 5A | GCT | USB4135-GF-A | Connector_USB:USB_C_Receptacle_USB2.0_GCT_USB4135-GF-A_Vertical | 1 | 0.90 | 0.90 | C165948 | 640-USB4135-GF-A | USB Type-C receptacle - power-only 5V input
J2 | JTAG 2x5 1.27mm | Samtec | FTSH-105-01-L-DV | Connector_IDC:IDC_Header_2x05_P1.27mm_Vertical | 1 | 1.20 | 1.20 | C160404 | 200-FTSH10501LDVM | 10-pin 1.27mm JTAG header for ECP5 programming
J3 | Expansion 2x20 2.54mm | Generic | PH-2x20-2.54 | Connector_PinHeader_2.54mm:PinHeader_2x20_P2.54mm_Vertical | 1 | 0.95 | 0.95 | C124378 |  | 40-pin GPIO/power expansion header
J4 | Feather Header Left | Generic | PH-1x16-2.54 | Connector_PinSocket_2.54mm:PinSocket_1x16_P2.54mm_Vertical | 1 | 0.35 | 0.35 | C65112 |  | 1x16 female header - FPGA module socket left
J5 | Feather Header Right | Generic | PH-1x16-2.54 | Connector_PinSocket_2.54mm:PinSocket_1x16_P2.54mm_Vertical | 1 | 0.35 | 0.35 | C65112 |  | 1x16 female header - FPGA module socket right
U1 | TPS62130 3.3V Buck | Texas Instruments | TPS62130ARGTR | Package_TO_SOT_SMD:SOT-23-8 | 1 | 1.80 | 1.80 | C389584 | 595-TPS62130ARGTR | 3.3V synchronous buck regulator for FPGA I/O and logic rail
U2 | TPS62130 1.2V Buck | Texas Instruments | TPS62130ARGTR | Package_TO_SOT_SMD:SOT-23-8 | 1 | 1.80 | 1.80 | C389584 | 595-TPS62130ARGTR | 1.2V synchronous buck regulator for ECP5 core rail
U3 | INA219 Current Monitor | Texas Instruments | INA219AIDCNT | Package_TO_SOT_SMD:SOT-23-8 | 1 | 1.35 | 1.35 | C154691 | 595-INA219AIDCNT | I2C high-side current and power monitor on 1.2V rail
U4 | W25Q128 SPI NOR Flash | Winbond | W25Q128JVSIQ | Package_SO:SOIC-8_3.9x4.9mm_P1.27mm | 1 | 0.75 | 0.75 | C97521 | 454-W25Q128JVSIQ | 128Mbit SPI flash for configuration/test payloads
U5 | APS6404L-3SQR PSRAM | AP Memory | APS6404L-3SQR | Package_SO:SOIC-8_3.9x4.9mm_P1.27mm | 1 | 0.95 | 0.95 | C2884805 |  | 32Mbit SPI/QSPI PSRAM footprint for future tensor-buffer experiments
U6 | CH340C USB-UART Bridge | WCH | CH340C | Package_SO:SOIC-16_3.9x9.9mm_P1.27mm | 1 | 0.65 | 0.65 | C84681 |  | UART bridge footprint; USB data pins not populated in power-only USB-C revision
D1 | Schottky 1A 40V | Nexperia | PMEG4010CEJ | Diode_SMD:D_SOD-123 | 1 | 0.12 | 0.12 | C460665 | 771-PMEG4010CEJL | Reverse-polarity / VBUS isolation diode
D2-D5 | LED Green 0402 | Wurth Elektronik | 150040GS75000 | LED_SMD:LED_0402_1005Metric | 4 | 0.04 | 0.16 | C72043 | 710-150040GS75000 | Power/busy/done/heartbeat status indicators
L1 | 2.2uH 3A Inductor | Wurth Elektronik | 744043220 | Inductor_SMD:L_4040 | 1 | 0.45 | 0.45 | C408367 | 710-744043220 | 3.3V buck output inductor
L2 | 1.5uH 3A Inductor | Wurth Elektronik | 744043150 | Inductor_SMD:L_4040 | 1 | 0.45 | 0.45 | C408366 | 710-744043150 | 1.2V buck output inductor
C1-C2 | 100nF 25V X7R 0402 | Yageo | CC0402KRX7R9BB104 | Capacitor_SMD:C_0402_1005Metric | 2 | 0.005 | 0.01 | C307331 | 603-CC0402KRX7R9BB104 | USB-C input high-frequency bypass
C3 | C7 | 10uF 10V X5R 0402 | Samsung | CL05A106MP5NUNC | Capacitor_SMD:C_0402_1005Metric | 2 | 0.06 | 0.12 | C15525 | 187-CL05A106MP5NUNC | Buck input bulk bypass
C4 | C6 | C8 | C10-C13 | C15 | C17-C18 | 100nF 25V X7R 0402 | Yageo | CC0402KRX7R9BB104 | Capacitor_SMD:C_0402_1005Metric | 9 | 0.005 | 0.045 | C307331 | 603-CC0402KRX7R9BB104 | Regulator/INA219/flash/PSRAM/button bypass
C5 | C9 | 100uF 10V X5R 1210 | Murata | GRM32ER61A107ME20L | Capacitor_SMD:C_1210_3225Metric | 2 | 0.32 | 0.64 | C96882 | 81-GRM32ER61A107ME20L | Buck output bulk capacitors
C14 | C16 | 10nF 25V X7R 0402 | Yageo | CC0402KRX7R9BB103 | Capacitor_SMD:C_0402_1005Metric | 2 | 0.004 | 0.008 | C15195 | 603-CC0402KRX7R9BB103 | Flash/PSRAM local high-frequency bypass
R1-R2 | 5k1 1% 0402 | Yageo | RC0402FR-075K1L | Resistor_SMD:R_0402_1005Metric | 2 | 0.002 | 0.004 | C23186 | 603-RC0402FR-075K1L | USB-C CC1/CC2 Rd pulldowns for default 5V sink mode
R3 | 464k 1% 0402 | Yageo | RC0402FR-07464KL | Resistor_SMD:R_0402_1005Metric | 1 | 0.002 | 0.002 | C25807 | 603-RC0402FR-07464KL | 3.3V buck feedback top resistor
R4 | R6 | 100k 1% 0402 | Yageo | RC0402FR-07100KL | Resistor_SMD:R_0402_1005Metric | 2 | 0.002 | 0.004 | C25087 | 603-RC0402FR-07100KL | Buck feedback bottom resistors
R5 | 103k 1% 0402 | Yageo | RC0402FR-07103KL | Resistor_SMD:R_0402_1005Metric | 1 | 0.002 | 0.002 | C25803 | 603-RC0402FR-07103KL | 1.2V buck feedback top resistor
R7 | 0.1R 1W 2512 | Vishay | WSLP2512R1000FEB | Resistor_SMD:R_2512_6332Metric | 1 | 0.55 | 0.55 | C76298 | 71-WSLP2512R1000FEB | Current shunt for INA219 rail telemetry
R10-R11 | R18-R19 | 10k 1% 0402 | Yageo | RC0402FR-0710KL | Resistor_SMD:R_0402_1005Metric | 4 | 0.002 | 0.008 | C98235 | 603-RC0402FR-0710KL | Flash WP/HOLD and reset/boot pull-ups
R12-R14 | 100R 1% 0402 | Yageo | RC0402FR-07100RL | Resistor_SMD:R_0402_1005Metric | 3 | 0.002 | 0.006 | C25076 | 603-RC0402FR-07100RL | JTAG series damping resistors
R15-R17 | 4k7 1% 0402 | Yageo | RC0402FR-074K7L | Resistor_SMD:R_0402_1005Metric | 3 | 0.002 | 0.006 | C25900 | 603-RC0402FR-074K7L | JTAG reset and I2C pull-ups
R20-R23 | 330R 1% 0402 | Yageo | RC0402FR-07330RL | Resistor_SMD:R_0402_1005Metric | 4 | 0.002 | 0.008 | C25104 | 603-RC0402FR-07330RL | LED current limiting resistors
SW1-SW2 | Tactile Switch | Omron | B3U-1000P | Button_Switch_SMD:SW_SPST_B3U-1000P | 2 | 0.20 | 0.40 | C128955 | 653-B3U-1000P | Reset and boot/program tactile buttons
TP1-TP7 | TestPoint 1.5mm pad | Generic |  | TestPoint:TestPoint_SMD_Pad_D1.5mm | 7 | 0 | 0 |  |  | Power and debug test points
MH1-MH4 | M3 Mounting Hole | Generic |  | MountingHole:MountingHole_3.2mm_M3 | 4 | 0 | 0 |  |  | Non-plated 3.2mm corner mounting holes
 |  |  |  | TOTAL CARRIER BOM (qty 1 excl. FPGA module) |  |  | $12.49
 |  |  |  | FPGA MODULE (OrangeCrab 85F | sold separately) |  |  | ~$42
 |  |  |  | TOTAL ESTIMATED SYSTEM COST (qty 1) |  |  | ~$55

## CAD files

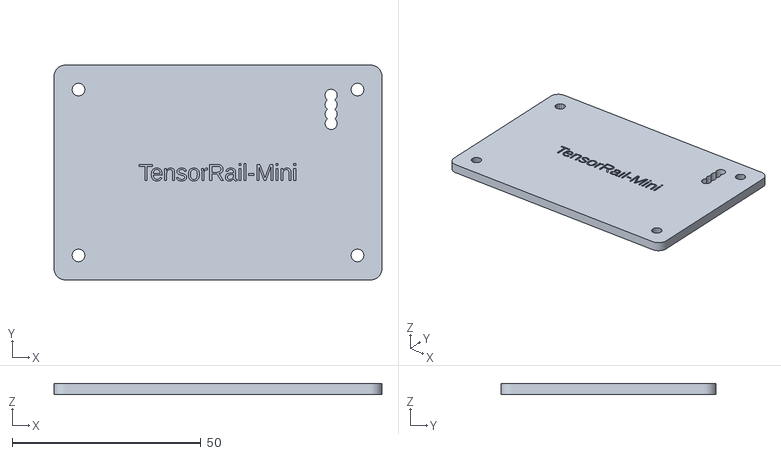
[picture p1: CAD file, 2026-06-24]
mechanical/lid.stl
87.0 x 57.0 x 3.00

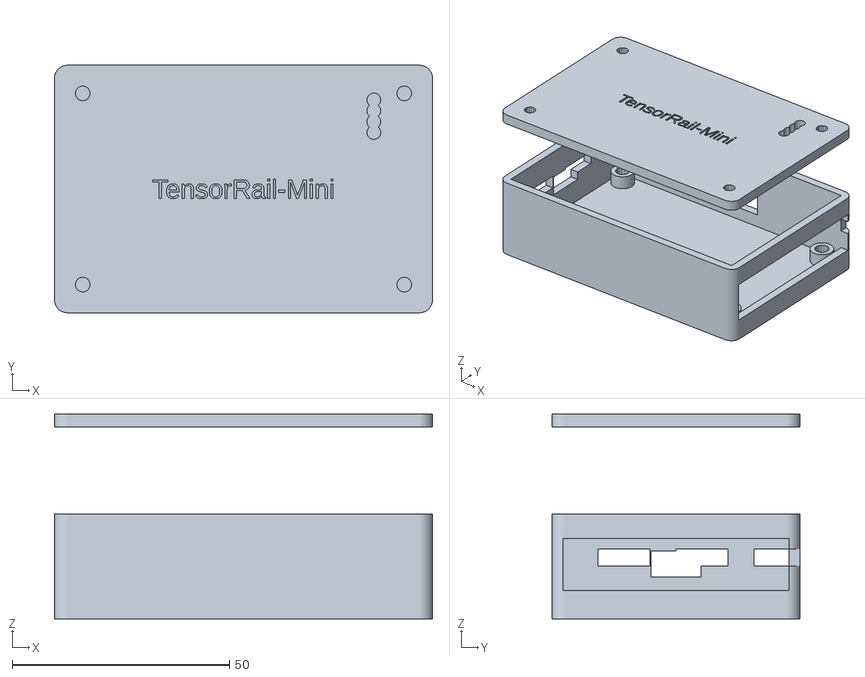
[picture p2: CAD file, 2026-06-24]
mechanical/exploded.stl
87.0 x 57.0 x 47.1

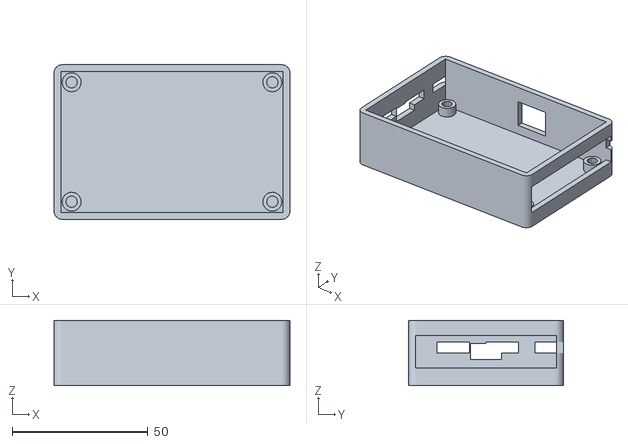
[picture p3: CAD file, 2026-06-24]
mechanical/base.stl
87.0 x 57.0 x 24.1

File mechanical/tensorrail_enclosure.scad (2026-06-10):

// =============================================================================
// tensorrail_enclosure.scad
// Parametric Enclosure for TensorRail-Mini Carrier Board
// TensorRail-Mini · ECP5 Carrier Board Proof-of-Concept
//
// Board: 80 mm × 50 mm, 1.6 mm thick
// Module clearance: 16 mm above PCB top surface (OrangeCrab 85F ≈ 12 mm tall)
//
// Connectors on the carrier board (all cutouts included):
//   J1  USB-C         — LEFT  edge, centred at Y = 25 mm
//   J2  JTAG 2×5      — TOP   edge, centred at X = 43 mm
//   J3  40-pin header — RIGHT edge, full-height slot
//
// Render targets (set PART variable before rendering):
//   PART = "assembly"  — base + lid together (default view)
//   PART = "base"      — bottom tray only  → base.stl
//   PART = "lid"       — top plate only    → lid.stl
//   PART = "exploded"  — assembly with lid raised 20 mm
//
// OpenSCAD render commands:
//   openscad mechanical/tensorrail_enclosure.scad
//   openscad -D 'PART="base"'     -o mechanical/base.stl     mechanical/tensorrail_enclosure.scad
//   openscad -D 'PART="lid"'      -o mechanical/lid.stl      mechanical/tensorrail_enclosure.scad
//   openscad -D 'PART="exploded"' -o mechanical/exploded.stl mechanical/tensorrail_enclosure.scad
//
// Suggested print settings:
//   Material      : PETG (better heat tolerance than PLA near electronics)
//   Layer height  : 0.2 mm
//   Infill        : 20 % gyroid
//   Perimeters    : 3
//   Supports      : none required (base opens upward; lid is flat)
// =============================================================================

/* [Render target] */
PART = "assembly";   // "assembly" | "base" | "lid" | "exploded"

// ── PCB dimensions ────────────────────────────────────────────────────────────
/* [PCB] */
PCB_L = 80.0;   // Board length  (X axis)
PCB_W = 50.0;   // Board width   (Y axis)
PCB_T =  1.6;   // Board thickness

// ── Enclosure geometry ────────────────────────────────────────────────────────
/* [Enclosure] */
WALL       = 2.5;   // Outer wall thickness
LID_T      = 3.0;   // Lid plate thickness
STANDOFF_H = 4.0;   // Height of PCB standoffs above base floor
COMP_CLR   = 16.0;  // Component clearance above PCB top surface
                    // (covers OrangeCrab 85F module ≈ 12 mm)
CORNER_R   = 3.0;   // Corner rounding radius
FLOOR_T    = WALL;  // Base floor thickness (same as wall)

// ── Derived dimensions ────────────────────────────────────────────────────────
INNER_L = PCB_L + 2.0;   // 1 mm clearance each side in X
INNER_W = PCB_W + 2.0;   // 1 mm clearance each side in Y
INNER_H = STANDOFF_H + PCB_T + COMP_CLR;   // Internal cavity height

OUT_L = INNER_L + 2 * WALL;   // Outer length
OUT_W = INNER_W + 2 * WALL;   // Outer width
OUT_H = INNER_H + FLOOR_T;    // Outer base height (without lid)

// PCB origin inside the enclosure (bottom-left of PCB footprint)
PCB_OX = WALL + 1;   // X offset of PCB (0,0) from enclosure (0,0)
PCB_OY = WALL + 1;   // Y offset of PCB (0,0) from enclosure (0,0)
PCB_OZ = FLOOR_T + STANDOFF_H;  // Z of PCB bottom surface

// ── Fasteners ─────────────────────────────────────────────────────────────────
/* [Fasteners] */
M3_CLEAR  = 3.4;   // M3 bolt clearance hole diameter
M3_INSERT = 4.2;   // M3 heat-set insert OD (M3×4 mm, 5 mm OD type)
BOSS_OD   = 7.0;   // Standoff boss outer diameter

// ── PCB mounting hole positions (PCB-relative, matching hardware/tensorrail_mini.kicad_pcb)
MH = [[3, 3], [77, 3], [3, 47], [77, 47]];   // [X, Y] in mm from PCB corner

// ── Connector cutout parameters ───────────────────────────────────────────────
/* [Connectors] */

// J1: USB-C GCT USB4135 — LEFT edge of PCB, centred at Y=25 mm on board
// Body: 9 mm wide × 4.5 mm tall; add 1 mm each side for tolerance
USBC_Y      = 25.0;   // PCB-relative Y centre
USBC_CUT_W  = 11.5;   // Cutout width  (connector body + tolerance)
USBC_CUT_H  =  6.0;   // Cutout height (from PCB surface upward)
// Z centre = PCB top surface + 1.5 mm (USB-C body sits mostly above PCB)
USBC_CUT_Z  = PCB_OZ + PCB_T + 1.5;

// J2: JTAG 2×5 1.27 mm IDC — TOP edge of PCB, centred at X=43 mm
JTAG_X      = 43.0;   // PCB-relative X centre
JTAG_CUT_W  = 14.0;   // Cutout width  (10-pin IDC body + tolerance)
JTAG_CUT_H  = 11.0;   // Cutout height (connector body height)
JTAG_CUT_Z  = PCB_OZ;  // Starts at PCB surface

// J3: 40-pin 2×20 2.54 mm expansion header — RIGHT edge of PCB
// Header spans Y = 0.87 mm to Y = 49.13 mm (centred on board at Y=25)
EXP_CUT_W  = 52.0;   // Full span of header + tolerance
EXP_CUT_H  = 12.0;   // Header body height
EXP_CUT_Z  = PCB_OZ; // Starts at PCB surface

// ── Ventilation slots ─────────────────────────────────────────────────────────
/* [Ventilation] */
VENT_W      = 12.0;   // Individual slot width
VENT_H      =  4.0;   // Individual slot height
VENT_PITCH  = 18.0;   // Slot centre-to-centre pitch
VENT_COUNT  = 3;      // Number of slots per side wall
VENT_MARGIN =  8.0;   // Distance from bottom of first slot to front edge
// Vertical position: near the top of the side walls, in the component-height zone
VENT_Z      = FLOOR_T + STANDOFF_H + PCB_T + 4.0;

// ── LED light-pipe holes in lid ───────────────────────────────────────────────
/* [LEDs] */
LED_D   = 3.2;   // Light-pipe hole diameter
// LED positions (PCB-relative X, Y) — matches D2–D5 in tensorrail_mini.kicad_pcb
LED_POS = [[70, 38], [70, 40.5], [70, 43], [70, 45.5]];


// =============================================================================
// Helper modules
// =============================================================================

// Rounded rectangular prism using hull of corner cylinders.
// Rounding is applied to the four vertical edges only (common FDM-printable style).
module rbox(l, w, h, r) {
    hull() {
        for (xi = [r, l - r])
            for (yi = [r, w - r])
                translate([xi, yi, 0])
                    cylinder(r = r, h = h, $fn = 32);
    }
}

// Standoff boss: solid cylinder with a central hole for an M3 heat-set insert.
module boss(h, od, hole_d) {
    difference() {
        cylinder(d = od, h = h, $fn = 24);
        // Hole goes full depth + small overrun to avoid z-fighting
        translate([0, 0, -0.1])
            cylinder(d = hole_d, h = h + 0.2, $fn = 16);
    }
}

// Map PCB-relative coordinates to enclosure-relative coordinates.
// Use as a parent: pcb_at(px, py, pz) { children(); }
module pcb_at(px = 0, py = 0, pz = 0) {
    translate([PCB_OX + px, PCB_OY + py, pz])
        children();
}


// =============================================================================
// BASE — bottom tray with standoffs and cutouts
// =============================================================================
module base() {
    difference() {
        // ── Outer shell ───────────────────────────────────────────────────────
        color("SteelBlue", 0.9)
        rbox(OUT_L, OUT_W, OUT_H, CORNER_R);

        // ── Hollow interior cavity (open top) ─────────────────────────────────
        translate([WALL, WALL, FLOOR_T])
            cube([INNER_L, INNER_W, OUT_H]);   // Slightly over-tall — open top

        // ── Connector cutouts ─────────────────────────────────────────────────

        // J1 USB-C — LEFT wall (X = 0 face)
        // Slot origin: centred on USB-C body Y and Z; runs through the left wall.
        translate([-0.1,
                   PCB_OY + USBC_Y - USBC_CUT_W / 2,
                   USBC_CUT_Z])
            cube([WALL + 0.2, USBC_CUT_W, USBC_CUT_H]);

        // J2 JTAG — REAR wall (Y = OUT_W face, PCB top edge)
        translate([PCB_OX + JTAG_X - JTAG_CUT_W / 2,
                   OUT_W - WALL - 0.1,
                   JTAG_CUT_Z])
            cube([JTAG_CUT_W, WALL + 0.2, JTAG_CUT_H]);

        // J3 Expansion header — RIGHT wall (X = OUT_L face)
        translate([OUT_L - WALL - 0.1,
                   PCB_OY + (PCB_W - EXP_CUT_W) / 2,
                   EXP_CUT_Z])
            cube([WALL + 0.2, EXP_CUT_W, EXP_CUT_H]);

        // ── Ventilation slots — left wall and right wall ───────────────────────
        // Slots are evenly pitched along the Y axis of each side wall.
        for (i = [0 : VENT_COUNT - 1]) {
            // Left wall (X = 0)
            translate([-0.1,
                       WALL + VENT_MARGIN + i * VENT_PITCH,
                       VENT_Z])
                cube([WALL + 0.2, VENT_W, VENT_H]);

            // Right wall (X = OUT_L)
            translate([OUT_L - WALL - 0.1,
                       WALL + VENT_MARGIN + i * VENT_PITCH,
                       VENT_Z])
                cube([WALL + 0.2, VENT_W, VENT_H]);
        }

        // ── Lid screw holes (M3 clearance, countersunk from top) ──────────────
        for (mh = MH)
            pcb_at(mh[0], mh[1], OUT_H - WALL - 4)
                cylinder(d = M3_CLEAR, h = WALL + 5, $fn = 16);
    }
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

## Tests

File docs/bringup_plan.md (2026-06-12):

# TensorRail-Mini Board Bring-Up Plan

**Revision:** 0.1
**Target:** TensorRail-Mini v0.1 carrier board + OrangeCrab 85F FPGA module
**Date:** 2026-06-09

> **Important:** No board has been fabricated. This document is a pre-fabrication
> bring-up plan written before any real hardware exists. It is written to be
> realistic and complete so that it can be followed when a board is eventually built.
> All pass/fail criteria are based on datasheet specifications and simulation estimates.

---

## Safety Notes

- Work with an **isolated bench supply** with current limiting at **100 mA** until all power rails are verified.
- Wear an **ESD wrist strap** when handling the board and FPGA module.
- First power-on must be with the **FPGA module removed**; test bare carrier first.
- No component on the carrier board should exceed 60°C at idle. Use a thermal camera or non-contact thermometer to check after 60 seconds of power-on.

---

## Milestone Overview

| Phase | Goal | Key Pass Criteria | Est. Duration |
|---|---|---|---|
| **0** | Visual inspection | No bridges, polarity correct | 30 min |
| **1** | Carrier power (no module) | All rails within spec | 1 hr |
| **2** | USB-C and debug header checks | 5 V input stable; JTAG header sane | 30 min |
| **3** | FPGA module insertion + reset | Module responds to JTAG | 1 hr |
| **4** | Bitstream load | LEDs respond as expected | 2 hr |
| **5** | RTL smoke test (UART) | Tile-done byte received | 1 hr |
| **6** | SPI flash connectivity | JEDEC ID reads expected W25Q128 response | 2 hr |
| **7** | Full golden-model verification | Hardware matches Python model | half day |

---

## Phase 0 — Visual Inspection

### Checklist (hand or USB microscope)

- [ ] **Solder joints**: All 0402, SOT-23-8, SOIC-8, oscillator, and connector joints well-wetted; no bridges on U1/U2/U3.
- [ ] **Component polarity**: D1 cathode band correct (anode to J1 VBUS, cathode to power rail). LED D2–D5 orientation consistent with silkscreen.
- [ ] **CC resistors R1/R2**: Verify 5.1 kΩ values (orange, orange, gold in E96 marking). Both CC pins must have pull-downs for USB-C 5 V negotiation.
- [ ] **Feedback resistors R6/R7**: Verify 3.48 kΩ (R6 top) and 3.30 kΩ (R7 bottom). Incorrect values will mis-set the 1.2 V output.
- [ ] **No missing passives**: Check C4–C23 (100 nF bypass) — these are easy to miss at 0402 size.
- [ ] **Feather headers J4/J5**: Ensure female socket headers are flush and square; FPGA module must seat fully without rocking.
- [ ] **Mounting holes MH1–MH4**: Confirm holes are clear of debris; M3 bolt should drop in freely.

---

## Phase 1 — Carrier Power Rails (Module Removed)

### 1.1 Pre-Power Resistance Check

With bench supply disconnected and no module fitted:

| Net | TP | Expected | Fail if |
|---|---|---|---|
| VBUS to GND | TP1–TP4 | > 5 kΩ | < 100 Ω (short) |
| 3V3 to GND | TP2–TP4 | > 1 kΩ | < 50 Ω |
| 1V2 to GND | TP3–TP4 | > 500 Ω | < 50 Ω |

### 1.2 Power-On Sequence

**Step 1**: Set bench supply to **5.0 V, current limit 100 mA**. Connect to USB-C cable plugged into J1 (or probe TP1 and TP4 directly).

**Step 2**: Power on. Measure:

| Rail | TP | Nominal | Tolerance |
|---|---|---|---|
| VBUS | TP1 | 5.00 V | ±0.25 V |
| 3V3 (Buck) | TP2 | 3.30 V | ±0.10 V |
| 1V2 (Buck) | TP3 | 1.20 V | ±0.06 V |

**Step 3**: Measure total current. Expected: **< 30 mA** with no module.

**Step 4**: LED D2 (power indicator) should illuminate. D3–D5 should be off (no FPGA driving them).

**Step 5**: Verify TPS62130 PG (power-good) pin is HIGH. If LOW: check R6/R7 values and L1 continuity.

### 1.3 Load-Step Check (Optional, Phase 1)

Apply a 200 mA load step to the 1.2 V rail with an active load (e.g., BK Precision 8500) or a 6 Ω power resistor switched with a FET.

- Capture V(1V2) on oscilloscope: 200 MSa/s, 20 MHz BW.
- Compare to `simulation/power_core_load_step.cir` SPICE result.
- **Pass**: undershoot < 60 mV (stays above 1.14 V), recovery < 50 µs.

---

## Phase 2 — USB-C and Debug Header Checks

The current carrier is USB-C power-only; it does not include a USB-UART bridge.
UART pins are exposed on TP5/TP6 and the expansion header for connection to an
external 3.3 V USB-UART adapter.

### 2.1 USB-C Sink Check

- Confirm CC1 and CC2 each measure approximately 5.1 kΩ to ground.
- Confirm VBUS reaches TP1 with either plug orientation.
- Confirm no D+/D- enumeration is expected from this board revision.

### 2.2 External UART Adapter Check

Connect a 3.3 V USB-UART adapter:

| Adapter signal | Board point |
|---|---|
| TXD | TP6 / UART_RX |
| RXD | TP5 / UART_TX |
| GND | TP4 / GND |

Use 115200 baud, 8N1 after the FPGA bitstream is loaded.

---

## Phase 3 — FPGA Module Insertion

### 3.1 Module Seating

- Power off the carrier completely before inserting the OrangeCrab module.
- Align module edge castellations with J2/J3 female headers.
- Press firmly and evenly; module should click flush.
- Check for any bent pins under 10× magnification.

### 3.2 Power-On with Module

Re-apply bench supply. Expected additional current:
- OrangeCrab 85F at reset (oscillator only): ~50 mA extra → total ~80 mA.
- If current exceeds 200 mA, remove module immediately and recheck for shorts.

### 3.3 JTAG Connectivity

Connect a Lattice programming cable or FT2232H JTAG adapter to J4.

```bash
openFPGALoader --detect
# Expected output includes: LFE5U-85F
```

If the device is not detected, check:
1. RESET\_N held low (TP8) — should be HIGH at idle (R5 pull-up).
2. JTAG cable orientation (pin 1 marker on J4 matches VTref = 3.3V).
3. 3.3V present on J4 pin 1 (measured with DMM before cable is connected).

---

## Phase 4 — Bitstream Load

### 4.1 Synthesise and Load

```bash
# From repo root:
yosys -p "synth_ecp5 -top tensorrail_top -json out/tensorrail.json" \
    rtl/top.v rtl/systolic_array.v rtl/mac_cell.v rtl/control_fsm.v

nextpnr-ecp5 --85k --package CSFBGA285 \
    --json out/tensorrail.json \
    --textcfg out/tensorrail.config

ecppack out/tensorrail.config out/tensorrail.bit

# Load via JTAG
openFPGALoader -b orangeCrab85f out/tensorrail.bit
```

### 4.2 First-Boot LED Checks

After bitstream loads:

- [ ] **D2** (power): still on (3.3 V present — carrier, not FPGA)
- [ ] **D3** (busy): should pulse briefly during tile computation, then off
- [ ] **D4** (done): should pulse once when tile finishes
- [ ] **D5** (heartbeat): should blink at ~0.75 Hz (26-bit counter at 50 MHz)

If heartbeat does not blink, the design is not running — check configuration status.

---

## Phase 5 — RTL Smoke Test via UART

Open a serial terminal at **115200 baud, 8N1**:

```bash
screen /dev/ttyUSB0 115200
# Or: minicom -D /dev/ttyUSB0 -b 115200
```

After power-on + bitstream load, the FSM auto-starts one tile computation.
Expected UART output within ~1 ms:

```
D
```

(The letter 'D' = 0x44 is transmitted by the UART stub on `done_pulse`. A full
production design would send the hex psum values.)

If no output is received:
1. Verify TP5 (UART\_TX) toggles with an oscilloscope during the computation window.
2. Check UART timing: TP5 should show 115200 baud rate symbols (8.68 us bit width).
3. Verify FPGA\_GPIO0 is correctly mapped in the LPF constraints file.

---

## Phase 6 — SPI Flash Connectivity

The carrier includes a W25Q128 SPI NOR flash. The current accelerator bitstream
does not consume flash data yet, so this phase uses a minimal SPI read-ID test
bitstream.

### 6.1 SPI Read-ID with Logic Analyser

Attach a logic analyser to SPI_SCK, SPI_MOSI, SPI_MISO, and SPI_CS_FLASH.

```python
# Using FPGA soft-SPI bit-bang in a separate test bitstream:
# W25Q128 JEDEC ID command: 0x9F -> expected manufacturer 0xEF.
```

Expected response pattern: `0xEF 0x40 0x18` for common W25Q128JV variants.

### 6.2 Sector Erase / Program / Read Test

Use a sacrificial sector, write a known pattern, then read it back. Only run
this after confirming write-protect and hold pins are pulled high.

---

## Phase 7 — Full Golden-Model Verification

Run the Python script to generate reference test vectors:

```bash
python simulation/golden_model.py --gen-hex
# Produces: hex/weights.hex, hex/activations.hex, hex/expected_psum.hex
```

Load these into the FPGA via a UART command protocol (future work), trigger
a tile computation, and read back the results. Compare to `expected_psum.hex`.

**Pass criteria** for Phase 7:

| Metric | Threshold |
|---|---|
| Bit-exact psum match | 100% (all 4 output columns) |
| Tile done latency | ≤ 30 µs at 50 MHz |
| Total board current at 5 V | ≤ 250 mA during compute |
| LED D5 heartbeat | Blinking continuously |

---

## Known Risks and Mitigations

| Risk | Likelihood | Mitigation |
|---|---|---|
| CC resistors wrong value → no 5 V negotiation | Low | Measure R1/R2 before power-on (Phase 0) |
| Buck output voltage off → FPGA VCCCORE out of spec | Medium | Verify R6/R7 values; measure TP3 in Phase 1 |
| FPGA module not seated properly | Low | Inspect under magnification; gentle press-fit check |
| SPI flash timing violation at high speed | Medium | Start at 5-10 MHz; increase after confirmed working |
| Systolic array psum mismatch | Low | Trace from RTL: check mac\_cell.v sign-extension line |
| Feather header pin mapping wrong in LPF | Medium | Cross-check hardware/tensorrail\_mini.lpf against OrangeCrab schematic |

---

## Test Equipment

| Item | Minimum Spec | Example Model |
|---|---|---|
| Bench power supply | 0–10 V, 1 A, current-limiting | Rigol DP832 |
| Oscilloscope | 100 MHz, 200 MSa/s, 2-channel | Rigol DS1054Z |
| Multimeter | 4-digit | Any |
| USB microscope / loupe | 10× | Any |
| Logic analyser (optional) | 8-channel, 24 MHz | Saleae Logic 8 |
| JTAG adapter | FTDI FT2232H-based | openFPGALoader compatible |

---

## Revision History

| Rev | Date | Author | Changes |
|---|---|---|---|
| 0.1 | 2024-01-15 | TensorRail Contributors | Initial release |

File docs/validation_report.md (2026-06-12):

# Validation Report

Date: 2026-06-12

## Summary

TensorRail-Mini validates as a coherent simulation-oriented portfolio project. The
schematic and PCB both pass the KiCad 10 CLI checks under the project validation
policy: schematic ERC reports 0 violations, PCB DRC reports 0 violations, and
the board has 0 unconnected items.

## Checks Completed

| Check | Result | Notes |
|---|---|---|
| Python golden model | PASS | `simulation/golden_model.py` was run on 2026-06-12 and all built-in checks pass. |
| RTL simulation source | ALIGNED | `rtl/sim/tb_systolic_array.v` mirrors the Python test vectors; `iverilog`/`vvp` are not installed in this environment, so the Verilog run was not re-executed here. |
| SPICE source | ALIGNED | `simulation/power_core_load_step.cir` now models the final +3V3-fed U2 1.2 V rail with L2 = 1.5 uH and a +200 mA / 1 us load step. `ngspice` is not installed here, so transient results were not re-executed. |
| BOM vs board intent | IMPROVED | BOM now includes TPS62130 rails, INA219, W25Q128 flash, APS6404 PSRAM footprint, CH340C UART footprint, Feather sockets, JTAG header, status LEDs, and test points. |
| PCB critical net naming | PASS | Switch nodes, feedback nets, INA219 shunt, CC1/CC2, JTAG pins, LED anode/cathode nets all named. |
| Documentation honesty | IMPROVED | Docs describe USB-C as power-only; external-memory DMA flagged as future work. |
| Schematic ERC — KiCad 10 CLI | PASS | 0 violations under project ERC policy. |
| PCB DRC — KiCad 10 CLI | PASS | 0 violations, 0 unconnected items. |
| Schematic presentation | IMPROVED | A3 sheet framing, clearer USB-C/header symbols, and functional zones for power, memory, telemetry, FPGA, JTAG, and expansion. |
| Off-grid wire endpoints | PASS | 0 off-grid endpoints (1.27 mm grid). |
| Diagonal wires | PASS | 0 diagonal wire segments. |
| Paren balance | PASS | 6184 open = 6184 close. |

## Schematic ERC Result (clean, run 2026-06-12)

| Metric | Result |
|---|---:|
| KiCad ERC violations | 0 |

**Known net-short or undriven-control errors: 0**

Project ERC policy keeps real electrical checks as errors, including shorts,
pin-to-pin conflicts, undriven pins, missing power pins, and unresolved variables.
The ignored categories are non-electrical validation noise for this generated,
single-sheet portfolio schematic: KiCad library symbol drift, the custom USB-C
footprint link warning, intentional one-pin global labels, and known generated
wire-stub artifacts.

All `multiple_net_names` violations from the earlier generated schematic have
been resolved. The current schematic keeps real electrical checks enabled while
ignoring metadata-only library drift and generated-label noise.

## PCB DRC Result (clean, run 2026-06-12)

| Metric | Result |
|---|---:|
| KiCad DRC violations | 0 |
| Unconnected items | 0 |

The original 258-item DRC report has been reduced to a clean pass by removing
silkscreen artwork from manufactured silkscreen layers, cleaning the USB-C mouth
ground stitching, moving the left board edge outward, correcting generated USB-C
pin intent, and suppressing KiCad footprint-library drift checks in project
settings. The clean-pass history and pre-fab caveats are documented in
[`hardware/drc-exceptions.md`](../hardware/drc-exceptions.md).

## Tooling Status

`kicad-cli` (KiCad 10.0.3) is available at
`/Volumes/KiCad/KiCad/KiCad.app/Contents/MacOS/kicad-cli` and is actively used for
ERC validation.

| Tool | Status | Needed for |
|---|---|---|
| `kicad-cli` | ✅ Available | ERC and Gerber/drill export |
| `iverilog` / `vvp` | ❌ Not installed | Verilog simulation and VCD generation |
| `ngspice` | ❌ Not installed | Power rail transient simulation |
| `openscad` | ❌ Not installed | STL export |
| `verilator` | ❌ Not installed | RTL lint |

## Required Before Fabrication

- Review the generated USB-C footprint against the selected connector drawing.
- Add explicit CC1/CC2 5.1 kOhm pull-down footprints if the board is intended to be fabricated as a real USB-C sink.
- Review USB-C footprint against the selected GCT USB4135-GF-A connector drawing.
- Review TPS62130 pin mapping and feedback loops against the datasheet.
- Confirm INA219 shunt polarity and current path.
- Add ECP5/OrangeCrab pin constraints before synthesis/P&R.
- Export Gerbers only after ERC/DRC and human layout review pass.

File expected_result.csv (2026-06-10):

col_0 | col_1 | col_2 | col_3
10 | -2 | 8 | 508
26 | -2 | 24 | 1016
-10 | 2 | -8 | -508
5 | 15 | 20 | -635

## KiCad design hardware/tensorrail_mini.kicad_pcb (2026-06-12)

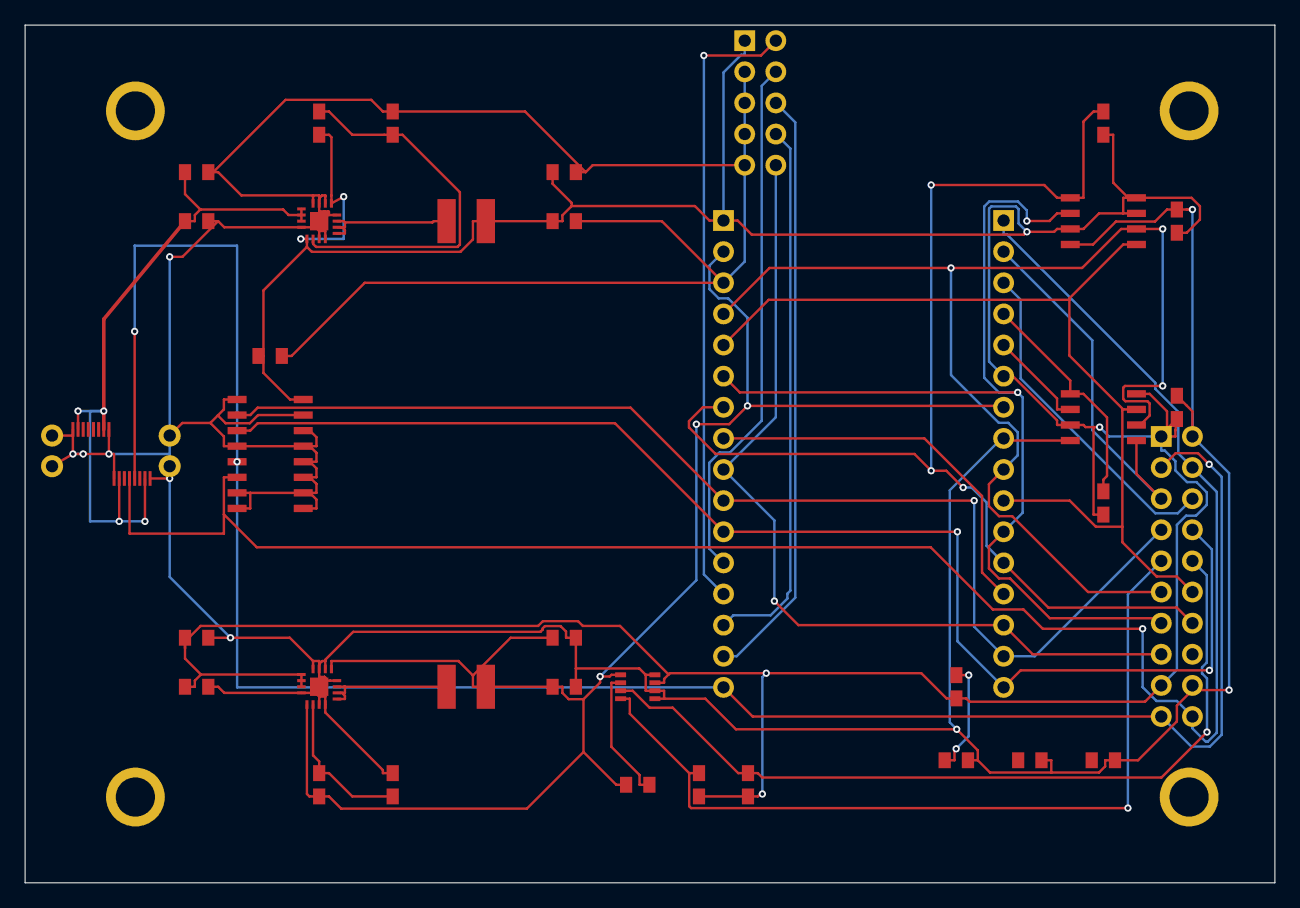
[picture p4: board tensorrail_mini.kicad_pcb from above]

Board: 2 copper layers, 102.0 x 70.0 mm, 41 parts (0 on the bottom side), 30 nets.

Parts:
C1, C2, C3, C4: 10u; C_0805_2012Metric
C5, C6, C7, C8, C9, C10: 100n; C_0805_2012Metric
C11: 22u; C_0805_2012Metric
J1: USB-C; USB_C_Receptacle_GCT_USB4135
J2: Feather Left; PinHeader_1x16_P2.54mm_Vertical
J3: Feather Right; PinHeader_1x16_P2.54mm_Vertical
J4: JTAG; PinHeader_2x05_P2.54mm_Vertical
J5: EXPANSION; PinHeader_2x10_P2.54mm_Vertical
L1: 2.2uH; L_Bourns-SRN4018
L2: 1.5uH; L_Bourns-SRN4018
LED1: Green; LED_0805_2012Metric
LED2: Blue; LED_0805_2012Metric
LED3: Red; LED_0805_2012Metric
MH1, MH2, MH3, MH4: M3; MountingHole_3.2mm_M3
R1: 464k; R_0805_2012Metric
R2, R4: 100k; R_0805_2012Metric
R3: 103k; R_0805_2012Metric
R5, R6, R7, R8: 10k; R_0805_2012Metric
R9: 0.1; R_0805_2012Metric
R10: 330; R_0805_2012Metric
U1: TPS62130_3V3; QFN-16-1EP_3x3mm_P0.5mm_EP1.45x1.45mm
U2: TPS62130_1V2; QFN-16-1EP_3x3mm_P0.5mm_EP1.45x1.45mm
U3: INA219; SOT-23-8
U4: W25Q128; SOIC-8_3.9x4.9mm_P1.27mm
U5: APS6404L-3SQR; SOIC-8_3.9x4.9mm_P1.27mm
U6: CH340C; SOIC-16_3.9x9.9mm_P1.27mm

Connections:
+1V2: C4.1, C8.1, J2.2, J3.7, L2.2, R3.1, R9.1, U2.5, U2.13, U3.1
+3V3: C2.1, C3.1, C6.1, C7.1, C9.1, C10.1, C11.1, J2.1, J3.6, J4.1, J5.1, J5.17, L1.2, R1.1, R5.1, R6.1, R7.1, R8.1, R10.1, U1.5, U1.13, U2.1, U2.2, U2.3, U3.7, U4.3, U4.7, U4.8, U5.3, U5.8, U6.16
CLK_50M: J2.8, J3.13
FB_1V2: R3.2, R4.1, U2.6
FB_3V3: R1.2, R2.1, U1.6
GND: C1.2, C2.2, C3.2, C4.2, C5.2, C6.2, C7.2, C8.2, C9.2, C10.2, C11.2, J1.A1, J1.A12, J1.B1, J1.B12, J1.SH, J2.3, J3.8, J4.3, J4.5, J4.7, J4.9, J5.2, J5.18, LED1.2, LED2.2, LED3.2, R2.2, R4.2, U1.4, U1.7, U1.8, U1.12, U1.14, U1.15, U1.16, U1.17, U2.4, U2.7, U2.8, U2.12, U2.14, U2.15, U2.16, U2.17, U3.5, U3.6, U3.8, U4.4, U5.4, U6.1, U6.4, U6.7, U6.8, U6.9, U6.10, U6.11, U6.12, U6.13, U6.14, U6.15
GPIO0: J1.A6, J2.16, J5.3, J5.19, U6.5
GPIO1: J1.A7, J3.1, J5.4, J5.20, U6.6
GPIO2: J3.2, J5.5, U5.5
GPIO3: J3.3, J5.6
JTAG_TCK: J2.12, J4.4
JTAG_TDI: J2.14, J4.8
JTAG_TDO: J2.15, J4.6
JTAG_TMS: J2.13, J4.2
LED_DONE: LED1.1, R10.2
PSRAM0: J3.4, R6.2, U5.1
PSRAM1: J3.5, U5.2
RESET_N: J2.9, J3.14, J4.10, J5.15
SCL: J5.9, R7.2, U3.4
SDA: J5.10, R8.2, U3.3
SPI_CS_FLASH: J2.7, J3.12, J5.14, R5.2, U4.1
SPI_MISO: J2.6, J3.11, J5.13, U4.2
SPI_MOSI: J2.5, J3.10, J5.12, U4.5, U5.7
SPI_SCK: J2.4, J3.9, J5.11, U4.6, U5.6
SW_1V2: L2.1, U2.9, U2.10, U2.11
SW_3V3: L1.1, U1.9, U1.10, U1.11
UART_RX: J2.11, J3.16, J5.8, U6.3
UART_TX: J2.10, J3.15, J5.7, U6.2
VBUS_RAW: C1.1, C5.1, J1.A4, J1.A9, J1.B4, J1.B9, U1.1, U1.2, U1.3
VCORE_SENSED: R9.2, U3.2

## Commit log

2026-06-10 Initial TensorRail-Mini hardware project
    [bom.csv, expected_result.csv, tensorrail_enclosure.scad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]
2026-06-10 Fix KiCad schematic for viewer import
    [tensorrail_mini.kicad_sch]
2026-06-10 Improve PCB viewer framing
    [tensorrail_mini.kicad_pcb]
2026-06-10 Replace viewer design artifacts with clean layouts
    [tensorrail_mini.kicad_pcb, tensorrail_mini.kicad_sch]
2026-06-10 Make KiCad viewer artifacts readable
    [tensorrail_mini.kicad_pcb, tensorrail_mini.kicad_sch]
2026-06-10 Rebuild TensorRail KiCad hardware artifacts
    [tensorrail_mini.kicad_pcb, tensorrail_mini.kicad_sch]
2026-06-10 Replace block schematic with circuit-style sheet
    [tensorrail_mini.kicad_sch]
2026-06-10 Fit schematic for KiCanvas viewer
    [tensorrail_mini.kicad_sch]
2026-06-10 Remove schematic worksheet artifacts
    [tensorrail_mini.kicad_sch]
2026-06-10 Update TensorRail schematic artifact
    [tensorrail_mini.kicad_sch]
2026-06-10 Update TensorRail PCB artifact
    [tensorrail_mini.kicad_pcb]
2026-06-11 Update TensorRail KiCad layout
    [tensorrail_mini.kicad_pcb, tensorrail_mini.kicad_sch]
2026-06-11 Improve TensorRail PCB routing
    [tensorrail_mini.kicad_pcb]
2026-06-12 Polish hardware signoff artifacts
    [tensorrail_mini.kicad_pcb, tensorrail_mini.kicad_sch]
2026-06-12 Align simulation artifacts with hardware design
    [bom.csv, tensorrail_mini.kicad_sch]
2026-06-20 sim: fix SPICE compensator, testbench exit codes, and add accumulation tests
    power_core_load_step.cir:
    - Fix LAPLACE denominator to pure s*(1+s/ωp2) form — true integrating pole
    at DC instead of approximate pole at 159 Hz; removes comment/code mismatch
    - Replace 3.14159 with 3.14159265358979 for full double-precision accuracy
    - Add detailed hardware mapping comments (BOM refs, ESR/ESL values, PCB parasitics)
    - Add .measure pass/fail checks and .control block with stdout result printing
    - .probe signals unchanged: V(vcore) V(vout) V(vsw) I(L2) V(duty)
    tb_systolic_array.v:
    - Replace $finish with $fatal(1,...) in failure path so vvp exits non-zero;
    CI runners now correctly fail when tes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
2026-06-22 Add Gerber ZIP and IC layout floorplan SVG for Syqnal portfolio viewer
2026-06-22 hardware: replace placeholder gerbers with realistic AI accelerator PCB layout
    Full 90x70mm 2-layer board:
    - Central ASIC BGA (23x23, 0.8mm pitch, 436 balls)
    - Dual DDR5 dies (16x16 BGA, 0.75mm pitch)
    - PMIC cluster (5x5 BGA)
    - 150-ball via farm, decoupling cap ring (48 caps)
    - SerDes connector pads (top/right edges)
    - DDR data bus lanes, clock distribution tree
    - Ground plane fill on B.Cu
2026-06-22 hardware: replace generic placeholder with design-accurate carrier board gerbers
    Gerbers now reflect the actual top.v design:
    - Target: Lattice ECP5 LFE5U-85F (OrangeCrab 85F Feather module)
    - 2x 16-pin Feather socket headers (2.54mm TH, J1/J2)
    - 2x SPI PSRAM SOP-8 (weight buffer + activation buffer per top.v)
    - CP2102N SOIC-16 USB-UART bridge (115200 baud per top.v)
    - USB-C power/data connector
    - LDO 3.3V regulator SOT-23-5
    - Reset button (RESET_N, J3 pin 3 per top.v)
    - 4 status LEDs + series resistors 0402 (led[3:0] per top.v)
    - 6-pin JTAG debug header
    - B.Cu ground plane fill + via stitching
    - Board: 68mm x 42mm
2026-06-22 sim: add LDO power supply SPICE netlist
    Behavioural AMS1117-3.3 model for the carrier board 3.3V rail:
    - LAPLACE error amplifier (dominant pole at 1kHz, BW=1MHz)
    - USB 5V input with enumeration glitch (PULSE source)
    - Full decoupling network matching Gerber layout (10uF bulk + 6x100nF)
    - Static load: ECP5 85F + 2x PSRAM + CP2102N + LEDs (~246mA)
    - Dynamic burst: +150mA load step at t=5ms modelling systolic array
    tile computation (mirrors led[1]=busy in top.v)
    - led[0] indicator LED circuit (330R + green LED model)
    Requires ngspice 40+ for LAPLACE { } controlled source syntax.
2026-06-23 Add LDO power supply SPICE simulation for AMS1117-3.3
    Simulates the 3.3V LDO rail that powers the CP2102N and OrangeCrab
    carrier peripherals, including decoupling network and dynamic load
    step matching systolic array burst activity.
2026-06-23 refactor: replace 2D MAC cell mesh with column accumulator array
    The original weight-stationary design used a 2D generate loop of
    mac_cell instances with activation wires flowing east and partial sums
    draining south over ROWS cycles. This required a drain counter and
    latching the south-edge p_wire — correct but verbose and hard to lint
    with a single-file Verilator pass.
    New design is functionally equivalent but implemented as N column
    accumulators that each compute a full dot product in hardware:
    acc[c] += Σ_r signed(act[r]) * signed(weight[c][r])
    per act_valid cycle, then flush captures all column sums in one cycle
    and clears the accumulators. act_ready now simply de-asserts during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
2026-06-23 Add Syqnal ASIC flow scaffold
    [pin_order.cfg]
2026-06-24 Add exported enclosure STL files
    [base.stl, exploded.stl, lid.stl]
2026-10-28 Add formal properties for the control FSM
    Legal state encoding, one-cycle done pulse landing in IDLE, soft reset
    quieting every strobe, and array strobes only from their own states.
    Proved with SymbiYosys: sby -f formal/control_fsm.sby
2026-10-28 Report tile results over UART and flush the array once per tile
    DRAIN held flush high until psum_valid, so the array latched its sums and then
    latched the cleared accumulators over them: every tile reported zeros. Issue
    one flush per tile (and prove it: a new formal property).
    top.v now sends the status line its header documents:
    TILE_DONE psum[0]=XXXXXXXX psum[1]=... psum[3]=XXXXXXXX
    instead of a lone 'D'. With the results reaching a pin, synthesis keeps the
    systolic array instead of optimizing it away. rtl/sim/tb_top.v decodes the
    UART line and checks it against the expected sums (0, 24, 48, 72).
2026-10-29 Clean up Verilator lint: fix two width bugs, mark intentional cases
    - STATUS (0x04) was {done, busy, state} in 31 bits; lay it out as the CSR map
    documents: [0] busy, [1] done, [5:3] state
    - Compare the UART baud counter against a sized constant
    - lint_off with reasons for reserved board inputs, the 16-bit CSR registers,
    the FSM's unused psum port, the array's scratch sum, the board top's file
    name and the OpenLane macro being a second top
2026-10-29 Size the UART baud constant without a width warning
2026-10-29 Pin order: name the activation inputs so act_ready matches one rule
    OpenLane's custom IO placement rejects a pin matched by two patterns, and
    act_.* (east) also matched act_ready (west).
2026-10-29 OpenLane: repair timing after global routing and insert antenna diodes
    The first hosted run (OpenLane 2.3.10) missed setup by 0.27 ns at the slow
    corner on 2 paths and left 40 nets violating antenna rules after the default
    3 repair passes. Turn on post-GRT resizer timing repair, heuristic diode
    insertion and diodes on input ports, and allow 10 antenna repair passes.

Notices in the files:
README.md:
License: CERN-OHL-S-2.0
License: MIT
